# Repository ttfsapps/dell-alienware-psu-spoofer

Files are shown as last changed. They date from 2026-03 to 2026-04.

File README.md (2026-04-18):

# Dell/Alienware PSU Spoofer 
Allows user to use any lab power supply to power a Dell or Alienware notebook pc by supplying the required Dell PSU ID string. Dell and Alienware computers require the ID string to run normally. Performance is throttled if no ID string is provided for power protection purposes. The spoofer is configurable to send the ID string that matches the input lab supply's power rating via dipswitches. 

## Hardware Required
Custom PCB design which uses an Atmel ATtiny85 microcontroller and OneWireHub to emulate a Maxim DS2502, a 1Kb Add-Only Memory device with a unique 48-bit serial number, programmable EPROM, and 1-Wire interface. The DS2502 is used by Dell and Alienware OEM PSU's to determine the PSU's wattage. It appears that the notebook pc's do not use any of the other information provided in the Dell ID string other than wattage.

## KiCad Files
[KiCad Schematic](kicad/dell_psu_spoofer.kicad_sch)

[KiCad PCB](kicad/dell_psu_spoofer.kicad_pcb)

[KiCad BOM](kicad/dell_psu_spoofer.csv)

[Gerber File](kicad/dell_psu_spoofer.kicad_pcb.zip)

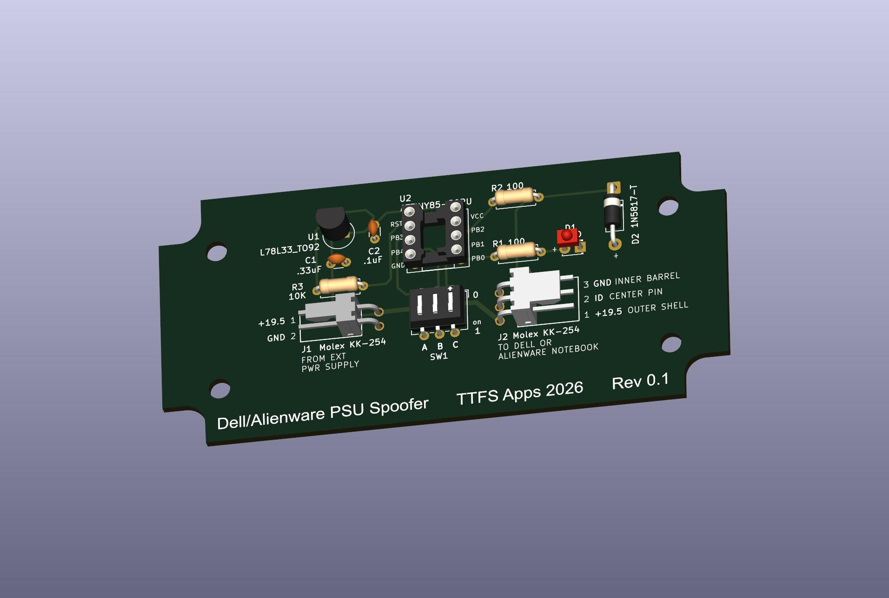
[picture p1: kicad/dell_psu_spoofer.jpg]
KiCad BOM


## Libraries Required
|Library|Function|
|:-----:|:-----:|
|[OneWireHub.h](https://github.com/orgua/OneWireHub)|OneWireHub library| 
|DS2502.h|included with OneWireHub library| 

## DIP Switch Settings
|A|B|C|Watts|
|:-----:|:---:|:---:|:-----:|
|0|0|0|75|
|0|0|1|100|
|0|1|0|125|
|0|1|1|150|
|1|0|0|175|
|1|0|1|200|
|1|1|0|225|
|1|1|1|250|

## Pin Names, Numbers, and Functions
|||||||||
|:--:|:--:|:--:|:--:|:--:|:--:|:--:|:--:|
|ATtiny85 Pin|5|1|7|6|3|2|ATtiny85 hardware pin numbers (reference only)|
|Pin Name|PB0|PB5/RST|PB2|PB1|PB4|PB3|ATtiny85/Arduino pin names|
|Arduino Pin #|0|5|2|1|4|3|Arduino IDE pin numbers (s/w uses these)|
|PCB Label|LED|RST|ID|A|B|C|Pin function|
|Function||not used|OneWire|Power Select|Power Select|Power Select|

TTFS Apps 2026

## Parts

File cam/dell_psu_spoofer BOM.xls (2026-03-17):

Reference | Description | Manufacturer | Manufacturer Part # | Quantity | Unit Price | Ext
J2 | CONN HEADER R/A 3POS 2.54MM | Molex | 22053031 | 1 | $0.22 | $0.22
 | CONN RCPT HSG 3POS 2.54MM | Molex | 22012037 | 1 | $0.13 | $0.13
J1 | CONN HEADER R/A 2POS 2.54MM | Molex | 22053021 | 1 | $0.16 | $0.16
 | CONN RCPT HSG 2POS 2.54MM | Molex | 22012027 | 1 | $0.10 | $0.10
 | CONN 22-30AWG CRIMP TIN | Molex | 8500032 | 5 | $0.11 | $0.54
U2 | IC MCU 8BIT 8KB FLASH 8DIP | Microchip Tech | ATTINY85-20PU | 1 | $1.66 | $1.66
 | MACHINE PIN SOCKET, IC, DIP, 8P | Adam Tech | ICM-308-1-GT-HT | 1 | $0.46 | $0.46
SW1 | SWITCH SLIDE DIP SPST 0.05A 24V | CTS Electrocomp | 208-3 | 1 | $0.69 | $0.69
D2 | DIODE SCHOTTKY 20V 1A DO41 | STMicroelectronics | 1N5817-T | 1 | $0.13 | $0.13
D1 | LED, RED |  |  | 1 | $0.10 | $0.10
U1 | IC REG LINEAR 3.3V 100MA TO92-3 | STMicroelectronics | L78L33ACZ | 1 | $0.27 | $0.27
C1 | CAP CER 0.1uF 50V X7R RADIAL | KEMET | C320C104K5R5TA | 1 | $0.17 | $0.17
C2 | CAP CER 0.33uF 50V X7R RADIAL | KEMET | C320C334M5U5TA | 1 | $0.17 | $0.17
R1, R2 | RES 100 OHM 1% 1/4W AXIAL | YAGEO | MFR-25FRF52-100R | 2 | $0.10 | $0.20
R3 | RES 10K OHM 1% 1/4W AXIAL | YAGEO | MFR-25FRF52-10KR | 1 | $0.10 | $0.10
 | SL ENCLOSURE W/O FEET, W/MB'S, /REC. BASE, TEXT COVER | Polycase | SL-30PRMBT | 1 | $4.26 | $4.26
 | #4-24 X 1/4" PAN HEAD PHILIPS / HI LO SCREW, 100 PAC | Polycase | SCREWS-MBR-100 | 4 | $0.04 | $0.17
 | TEST LEAD BANANA | Pomona Electronics | B-24-02 | 2 | $4.00 | $8.00
 | DC POWER ADAPTER DELL 7.4MM X 5.0MM PLUG PIGTAIL CABLE | Amazon | B09N91ZSQW | 1 | $3.75 | $3.75
 |  |  |  |  |  | $21.27

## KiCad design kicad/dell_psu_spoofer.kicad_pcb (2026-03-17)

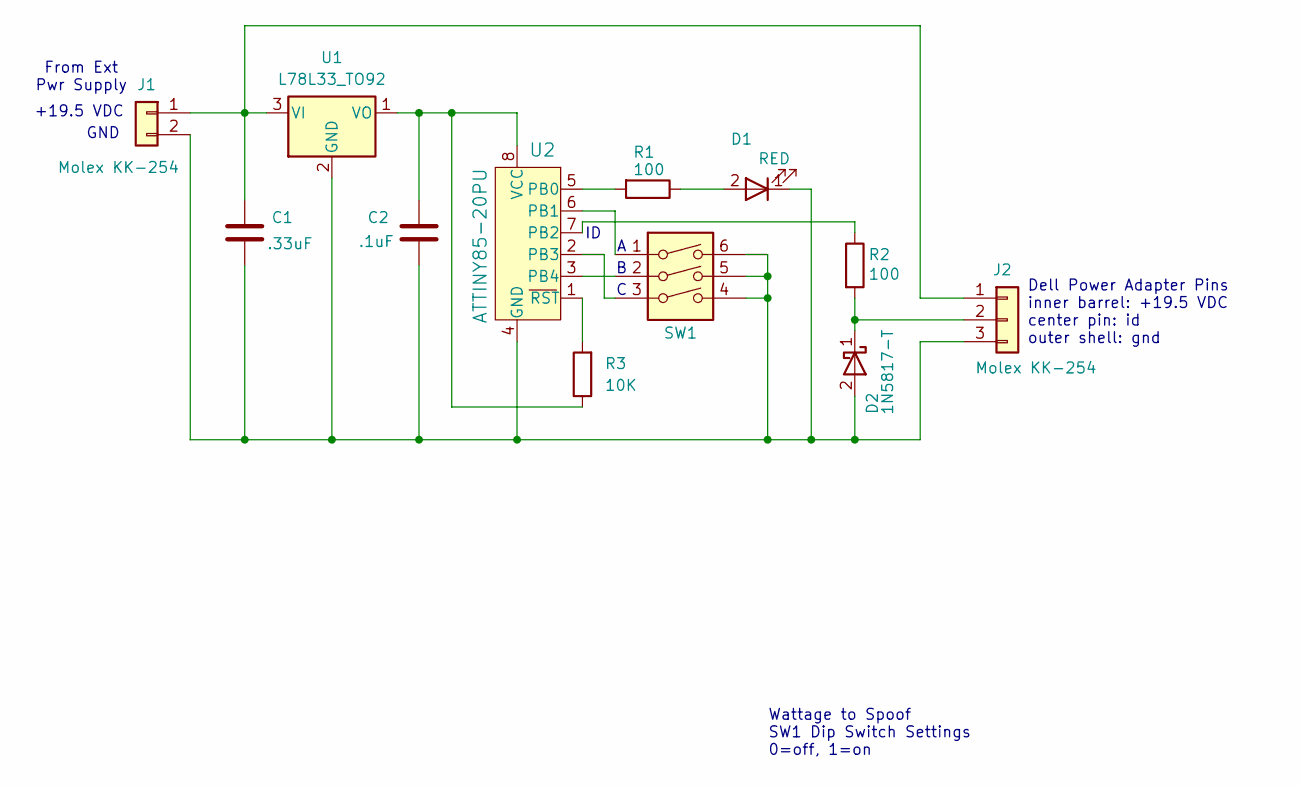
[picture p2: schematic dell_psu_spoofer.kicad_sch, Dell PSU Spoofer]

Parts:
C1: .33uF; C_Disc_D3.0mm_W1.6mm_P2.50mm
C2: .1uF; C_Disc_D3.0mm_W1.6mm_P2.50mm
D1: RED; LED_D1.8mm_W3.3mm_H2.4mm
D2: 1N5817-T; D_DO-41_SOD81_P10.16mm_Horizontal
J1: Molex KK-254; KK-254 CONN HEADER RA 2POS 2.54MM
J2: Molex KK-254; KK-254 CONN HEADER RA 3POS 2.54MM
R1, R2: 100; R_Axial_DIN0207_L6.3mm_D2.5mm_P7.62mm_Horizontal
R3: 10K; R_Axial_DIN0207_L6.3mm_D2.5mm_P7.62mm_Horizontal
SW1: SW_DIP_x04; SW_DIP_SPSTx03_Slide_6.7x9.18mm_W7.62mm_P2.54mm_LowProfile
U1: L78L33_TO92; TO-92_Inline
U2: ATTINY85-20PU; DIP-8_W7.62mm_Socket; MPN ATTINY85-20PU; Digi-Key_PN ATTINY85-20PU-ND

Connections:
unnamed: D1.2 (A), R1.1
unnamed: C1.2, C2.2, D1.1 (K), D2.2 (A), J1.2, J2.3, SW1.4, SW1.5, SW1.6, U1.2 (GND), U2.4 (GND)
unnamed: D2.1 (K), J2.2, R2.2
unnamed: C1.1, J1.1, J2.1, U1.3 (VI)
unnamed: C2.1, R3.1, U1.1 (VO), U2.8 (VCC)
unnamed: R1.2, U2.5 (PB0)
unnamed: SW1.1, U2.6 (PB1)
unnamed: R2.1, U2.7 (PB2)
unnamed: SW1.3, U2.2 (PB3)
unnamed: SW1.2, U2.3 (PB4)
unnamed: R3.2, U2.1 (RST)

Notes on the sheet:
Dell Power Adapter Pins inner barrel: +19.5 VDC center pin: id outer shell: gnd
+19.5 VDC
From Ext Pwr Supply
GND
Wattage to Spoof SW1 Dip Switch Settings 0=off, 1=on

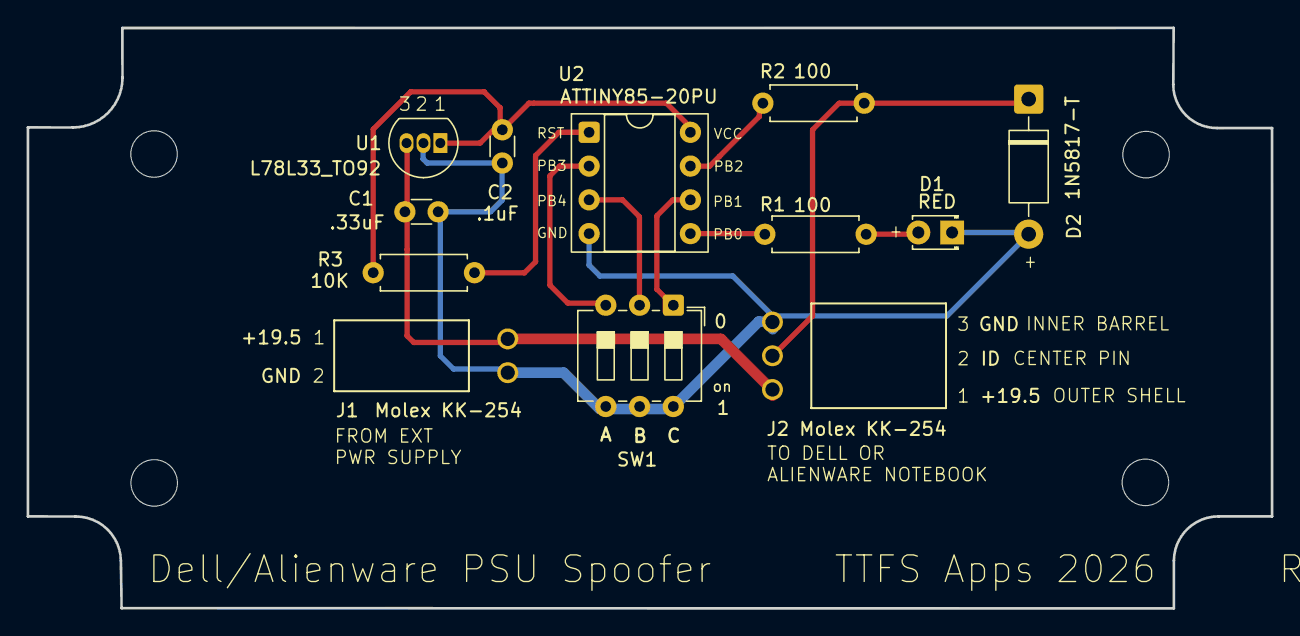
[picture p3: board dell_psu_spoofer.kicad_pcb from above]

Board: 2 copper layers, 93.6 x 43.7 mm, 12 parts (0 on the bottom side), 11 nets.

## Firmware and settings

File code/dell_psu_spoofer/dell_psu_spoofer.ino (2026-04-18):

// ****************************************************************************************
// Dell/Alienware PSU Spoofer 
//
// Allows any lab power supply to operate correctly with a Dell or Alienware notebook.
// The spoofer is configurable to send the ID string that matches the input lab supply's 
// power rating.

// Uses OneWireHub to emulate a Maxim DS2502, a 1Kb Add-Only Memory device 
// with a unique 48-bit serial number, programmable EPROM, and 1-Wire interface.
//
// KiCad Files
// dell_psu_spoofer.kicad_sch
// dell_psu_spoofer.kicad_pcb
//
// Version 0.0   initial release for rev 0.0 pcb only
// Version 0.1   inverted logic to use internal pullup resistors of attiny85 - reliability
//               swapped pb5 and pb1 for c dipswitch pin to avoid rst conflict
//               requires rev 0.1 pcb or later
//               reduced min wattage and max wattage to 75W and 250W
//
// TTFS Apps 2026
// ****************************************************************************************

// ****************debug macros*************************
#define DEBUG 0   // 1 = enable debug, 0 = disable debug

#if DEBUG
  #define DEBUG_BEGIN(baud)   Serial.begin(baud)
  #define DEBUG_PRINT(x)      Serial.print(x)
  #define DEBUG_PRINTLN(x)    Serial.println(x)
#else
  #define DEBUG_BEGIN(baud)   do {} while(0)
  #define DEBUG_PRINT(x)      do {} while(0)
  #define DEBUG_PRINTLN(x)    do {} while(0)
#endif
// ****************debug macros*************************

// onewirehub emulates numerous devices including the ds2502 used by dell/alienware psu's
#include <OneWireHub.h> // onewire hub library https://github.com/orgua/OneWireHub
#include "DS2502.h"     // included with onewirehub library

// DIP Switch Settings
// A   B   C	WATTS
// ----------------
// 0   0   0   75
// 0   0   1   100
// 0   1   0   125
// 0   1   1   150
// 1   0   0   175
// 1   0   1   200
// 1   1   0   225
// 1   1   1   250

// Pin Names, Numbers, and Functions
// ATtiny Pin #       5      1      7      6      3      2      // ATtiny85 hardware pin numbers (reference only)
// Pin Name          PB0  PB5/RST  PB2    PB1    PB4    PB3     // ATtiny85/Arduino pin names
// Arduino Pin #      0      5      2      1      4      3      // Arduino IDE pin numbers (s/w uses these)
// Function          LED    RST    ID      A      B      C      // Pin function
//                          NOT    ONE    PWR    PWR    PWR
//                          USED   WIRE   SEL    SEL    SEL

// declare pins
constexpr uint8_t idPin{2};   // PB2 dell id
constexpr uint8_t ledPin{0};  // PB0 led

// create onewire hub
auto hub = OneWireHub(idPin);                             

// DS2502( family_code,  serial_1,  serial_2,  serial_3,  serial_4,  serial_5,  serial_6 );
auto dellPSURom = DS2502(0x09, 0x00, 0x00, 0x02, 0x25, 0x0D, 0x00); 

void setup() {

  // ******************
  // set up the spoofer
  // ******************

  // ************ debug code *************
  // verify 8mhz operation It should print: 8000000
  // If it prints 1000000, the attiny fuses aren't blown
  // and timing will fail.
  DEBUG_BEGIN(115200);   // serial baud rate
  DEBUG_PRINTLN(F_CPU);  // output attiny85 clock frequency
  // ************ debug code *************

  // declare pins
  constexpr uint8_t aPin{1};    // PB5 first bit of pwr select
  constexpr uint8_t bPin{4};    // PB4 second bit of pwr select
  constexpr uint8_t cPin{3};    // PB3 third bit of pwr select

  // dell id string parts
  String header = "DELL00AC";                                  // Dell ID header   DELL00AC
  String volts = "195";                                        // Volts*10         VVV 3 digits in tenths of volts eg. 19.5 = 195
  String watts = "075100125150175200225250";                   // Watts            WWW 3 digits
  String amps = "038051064077090103115128";                    // Amps*10          III 3 digits in tenths of amps eg. 5.1 = 051
  String serialNumber = "CN0123456789ABCDEA05";                // Serial number    CN0123456789ABCDEA05 random 23 character
  String dellPSUId = "DELL00ACWWWVVVIIICN0123456789ABCDEA05";  // Dell ID          DELL00ACWWWVVVIIICN0123456789ABCDEA05 40 characters
  char outBuffer[42] = "";                                     // dell id string + two crc bytes

  // set led pin
  pinMode(ledPin, OUTPUT);  // led

  // set onewire connection
  pinMode(idPin, INPUT);  // input mode, don't use internal pull-up resistor

  // set sense pins  for dip switch to digital input mode using internal pull up
  // note: rev 1 implements pull up logic
  pinMode(aPin, INPUT_PULLUP);  // first bit of pwr select
  pinMode(bPin, INPUT_PULLUP);  // second bit of pwr select
  pinMode(cPin, INPUT_PULLUP);  // third bit of pwr select

  // Fetch DIP Switch Settings new hardware inverts logic
  // calculate pointer to selected power based on aPin, bPin, and cPin vals
  uint8_t ptr = 4 * !digitalRead(aPin) + 2 * !digitalRead(bPin) + !digitalRead(cPin);
 
  // Build the identification string
  dellPSUId = header + watts.substring(ptr, ptr + 2) + volts + amps.substring(ptr, ptr + 2) + serialNumber;

  // Pad if needed
  while (dellPSUId.length() < 40) dellPSUId += ' ';

  // Calculate CRC
  uint16_t crc = crc16_arc_string(dellPSUId);

  uint8_t lowByte = crc & 0xFF;          // first CRC byte (little-endian)
  uint8_t highByte = (crc >> 8) & 0xFF;  // second CRC byte

  // Append raw crc bytes to the String (they may be non-printable!)
  // the crc bytes have to be in little-endian order
  // there is some debate as to whether all dell models use crc
  // now the string is 42 bytes long
  dellPSUId += (char)lowByte;           // second byte goes first
  dellPSUId += (char)highByte;          // first byte goes second

  // set up id string and stuff fake eeprom device
  dellPSUId.toCharArray(outBuffer, 42);
  dellPSURom.writeMemory((uint8_t *)outBuffer, 42, 0x00);

  // attach fake device to onewire hub
  hub.attach(dellPSURom);

}

void loop() {

  // ********************
  // start up the spoofer
  // ********************

  // signal life
  digitalWrite(ledPin, HIGH);  // LED on

  // onewirehub does all the hard work
  // Detects reset pulse from laptop
  // Answers presence
  // Handles Skip ROM (0xCC — Dell almost always uses this)
  // Responds to Read Memory (0xF0)
  // Provides bytes from the emulated memory 
  hub.poll();

}

uint16_t crc16_arc_string(const String &str) {

  // ******************************
  // routine tocalculate CRC-16/ARC
  // ******************************

  uint16_t crc = 0;                           // Start with crc = 0x0000

  // calculate crc
  // For each byte in the 40-byte string
  for (size_t i = 0; i < str.length(); i++) { 
    
    uint8_t byte = (uint8_t)str[i];           // fetch byte
    crc ^= (uint16_t)byte << 8;               // XOR the byte into the upper 8 bits
    
    // For each byte in the 40-byte str of crc (crc ^= byte << 8)
    for (uint8_t bit = 0; bit < 8; bit++) {   

    // If the current MSB (bit 15) is 1
      if (crc & 0x8000) {
        crc = (crc << 1) ^ 0x8005;            // then shift left 1 bit, then XOR with 0x8005
      } else {
        crc <<= 1;                            // else just shift left 1 bit
      }
    }

  }

  // return crc
  return crc;
}

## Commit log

2026-03-17 Draft in Progress
    Expanded README with hardware requirements, libraries, DIP switch settings, and pin functions.
2026-03-22 Draft in Progress
    Added links and images for KiCad files and BOM.
2026-04-18 Lowered power settings
2026-04-18 Lower power ranges
2026-04-18 Update DIP switch settings wattage values
